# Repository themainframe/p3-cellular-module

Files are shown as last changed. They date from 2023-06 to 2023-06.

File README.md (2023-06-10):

# GPD Pocket 3 Cellular Module

This is a plug-in cellular module for the [GPD Pocket 3](https://gpd.hk/gpdpocket3). It provides LTE Cat. 4 cellular connectivity using a Quectel EC25 (or compatible) module.

It's still a little bit of a prototype at this stage, but initial results are promising!

You can read more about it [on my blog](https://damow.net/gpd-pocket-3-cellular-module).

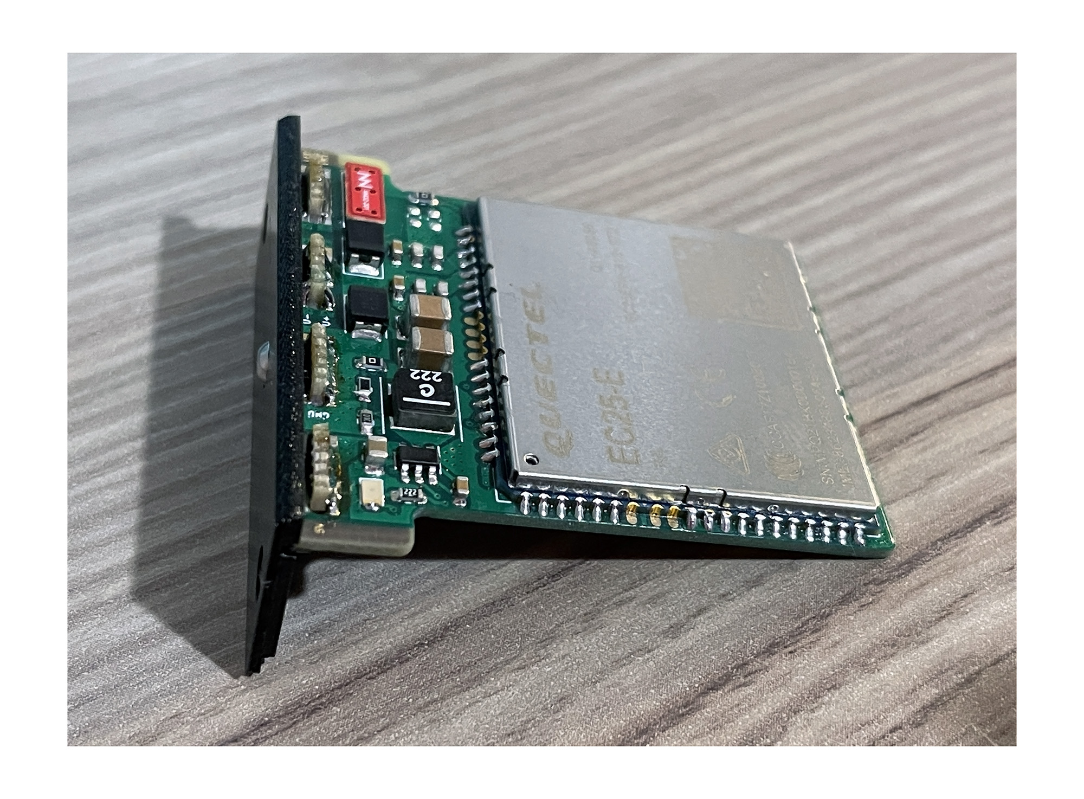
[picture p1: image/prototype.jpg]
Assembled prototype based on Rev1


## Stackup & BOM

4 layers. JLC JLC04101H-7628 Impedance Controlled FR4.

HTML BOMs can be found in the `bom/` directory.

## Questions?

Open an issue or drop me an email - `me@` my blog domain.

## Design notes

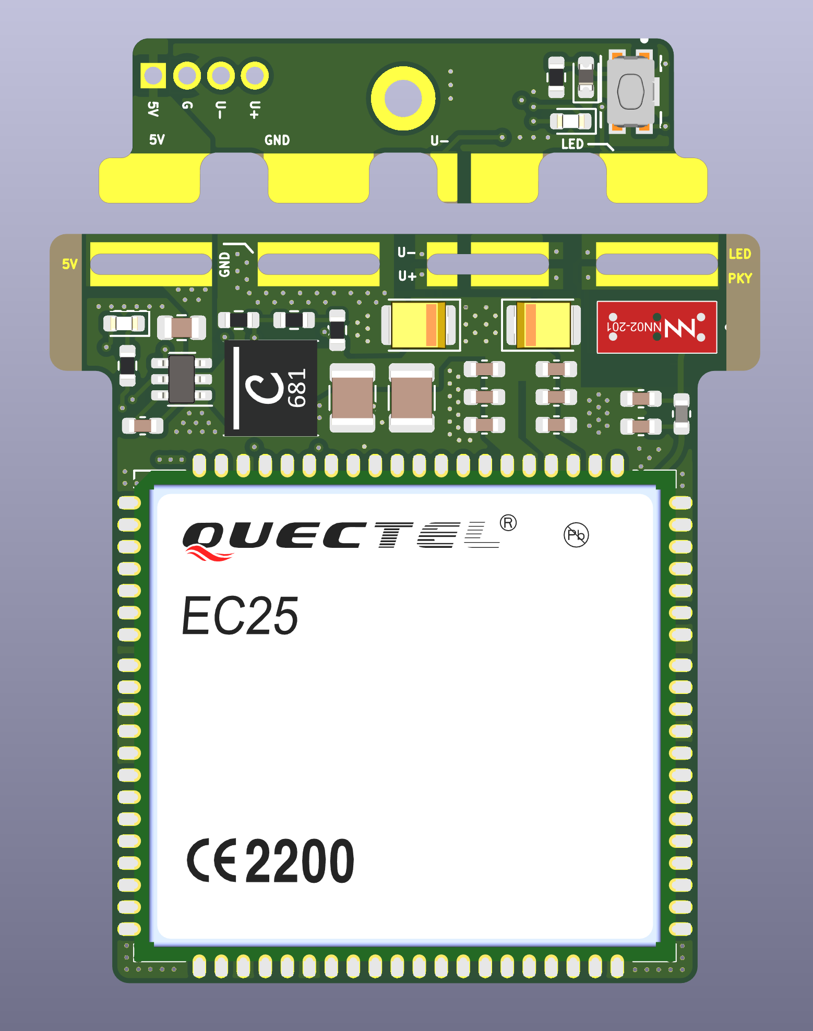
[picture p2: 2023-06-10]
gerber/rev2/2d/bottom.png

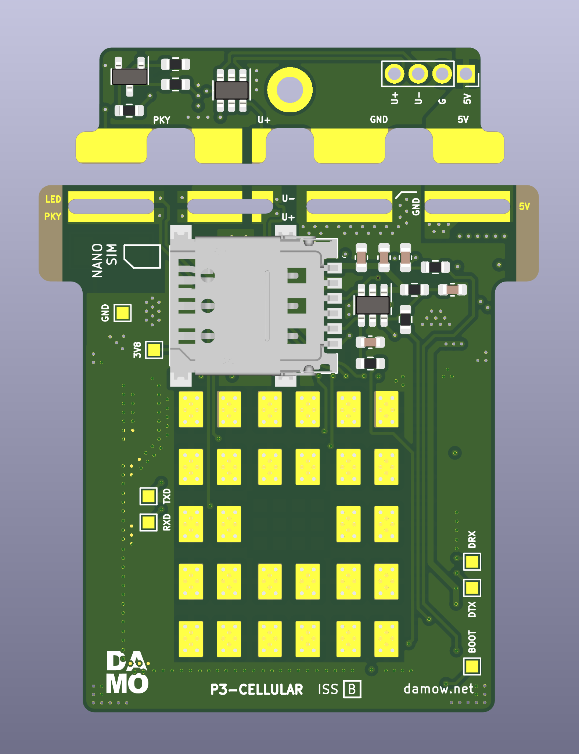
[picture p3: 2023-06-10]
gerber/rev2/2d/top.png

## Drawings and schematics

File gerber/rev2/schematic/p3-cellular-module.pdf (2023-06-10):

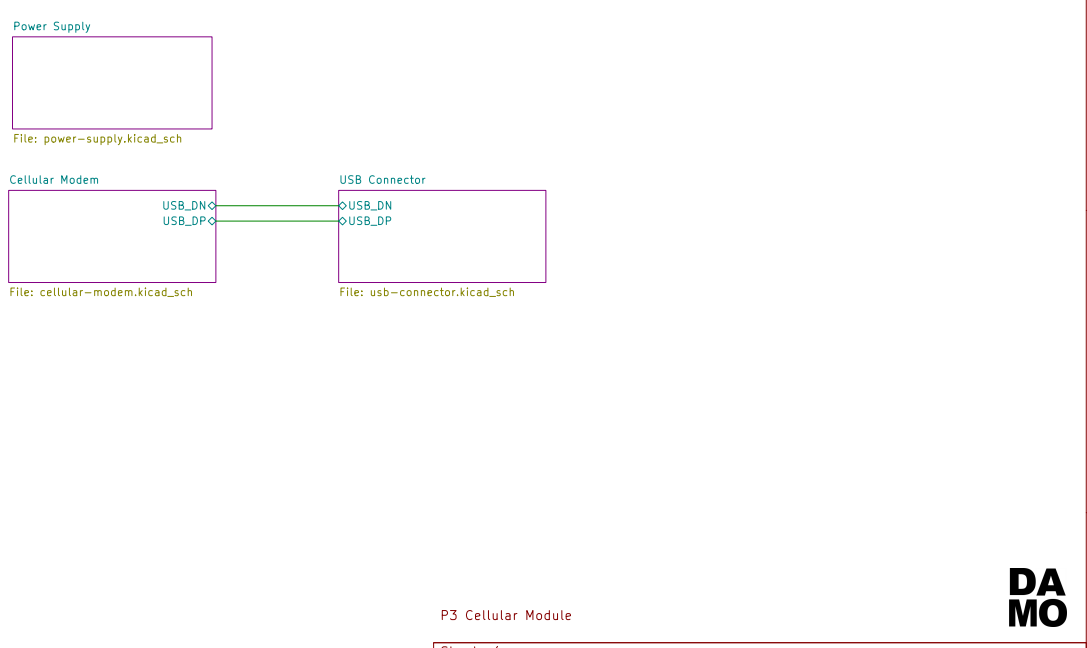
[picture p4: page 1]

USB_DP USB Connector File: usb-connector.kicad_sch

File: p3-cellular-module.kicad_sch Sheet: / P3 Cellular Module

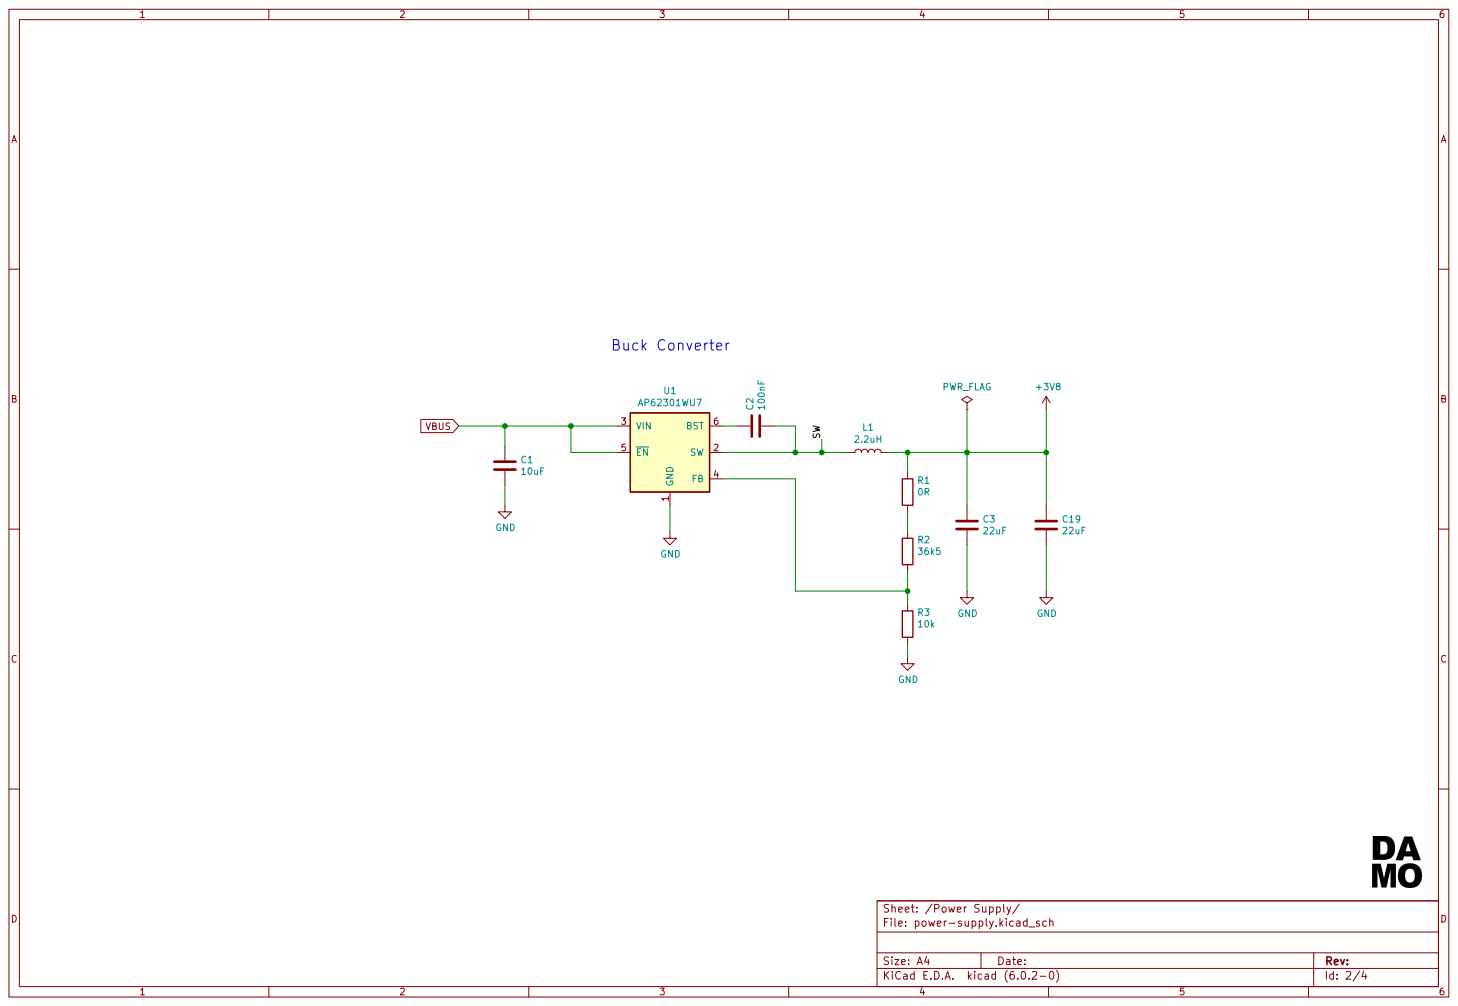
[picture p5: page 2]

1 SW 2 VIN 3 FB 4 ~{EN} 5 BST 6 U1 AP62301WU7 +3V8

Id: 2/4 File: power-supply.kicad_sch

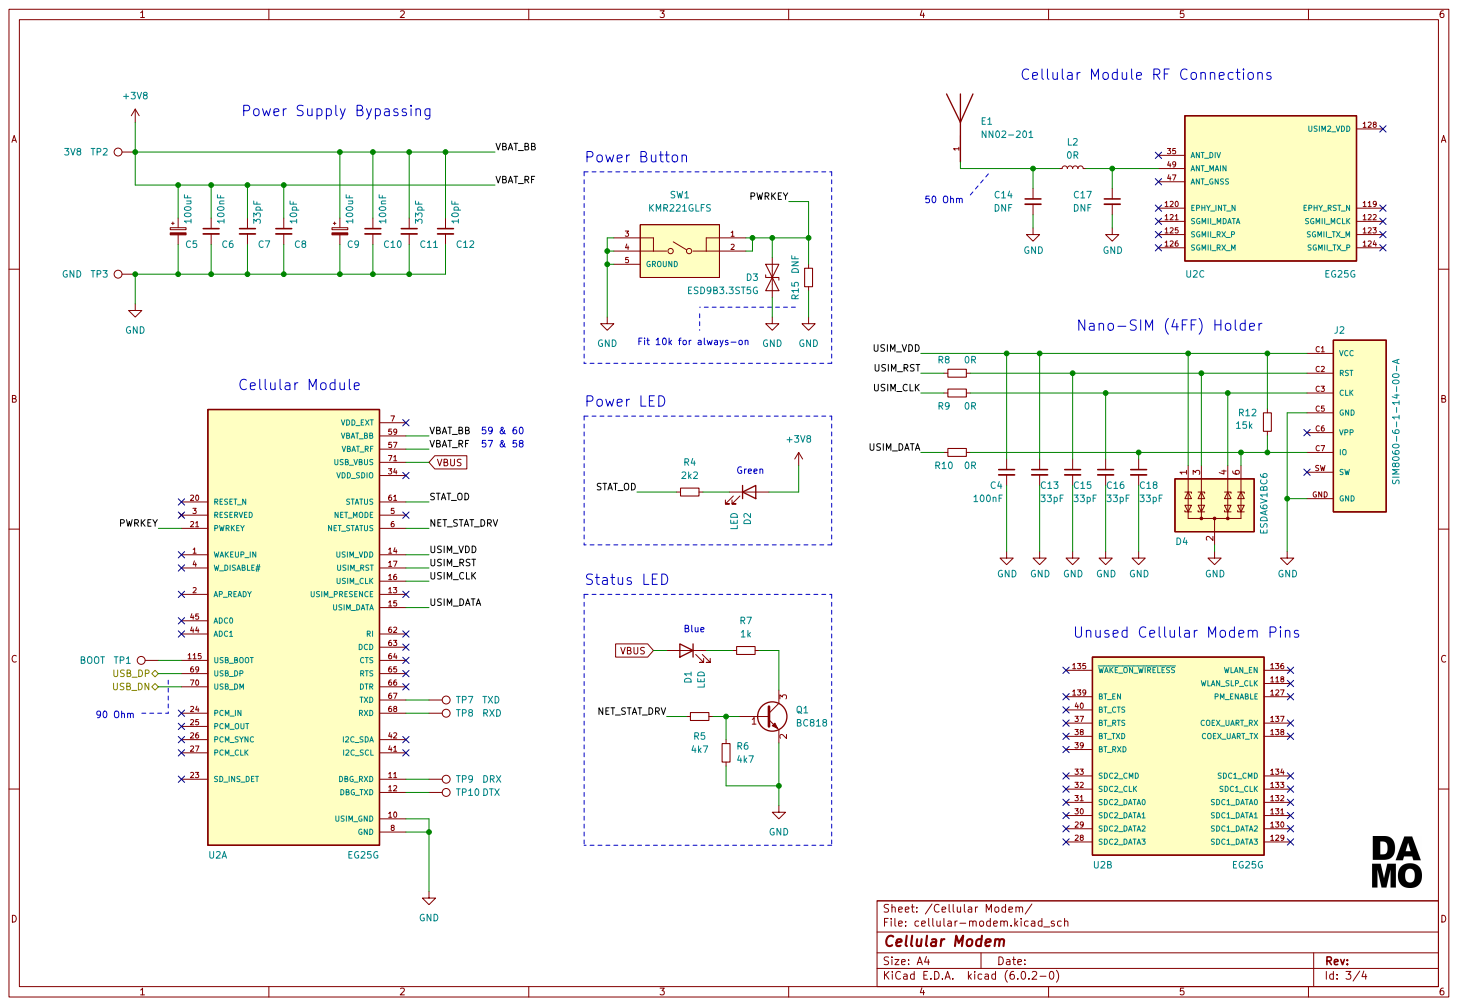
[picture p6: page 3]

Fit 10k for always-on

GND GND

Unused Cellular Modem Pins

File: cellular-modem.kicad_sch Sheet: /Cellular Modem/ GND

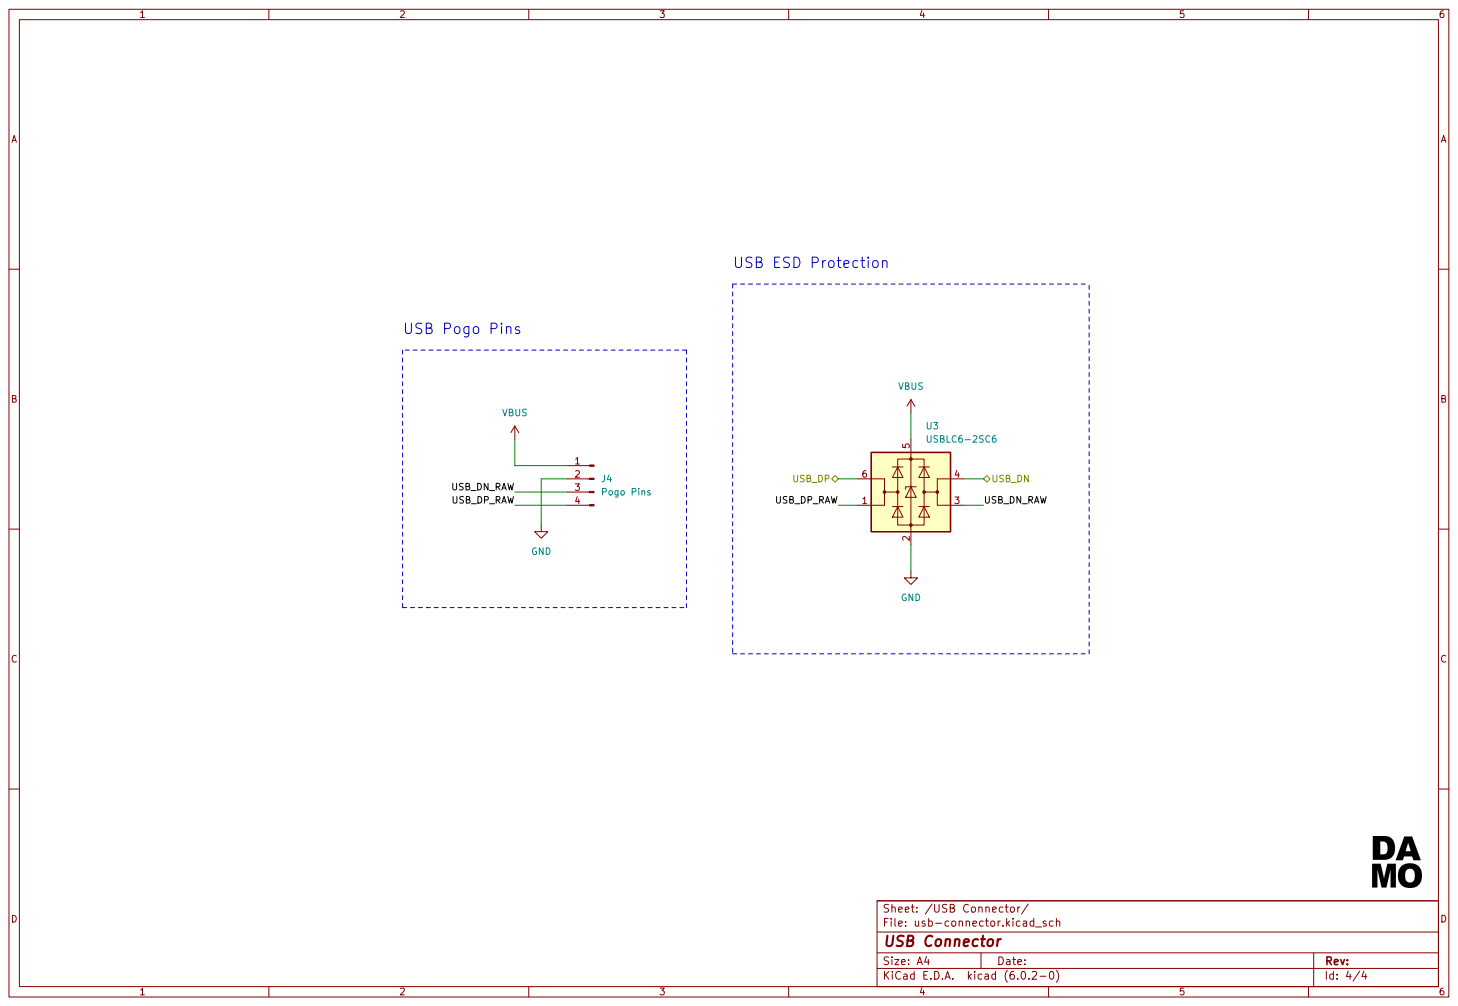
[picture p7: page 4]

File: usb-connector.kicad_sch Sheet: /USB Connector/ GND

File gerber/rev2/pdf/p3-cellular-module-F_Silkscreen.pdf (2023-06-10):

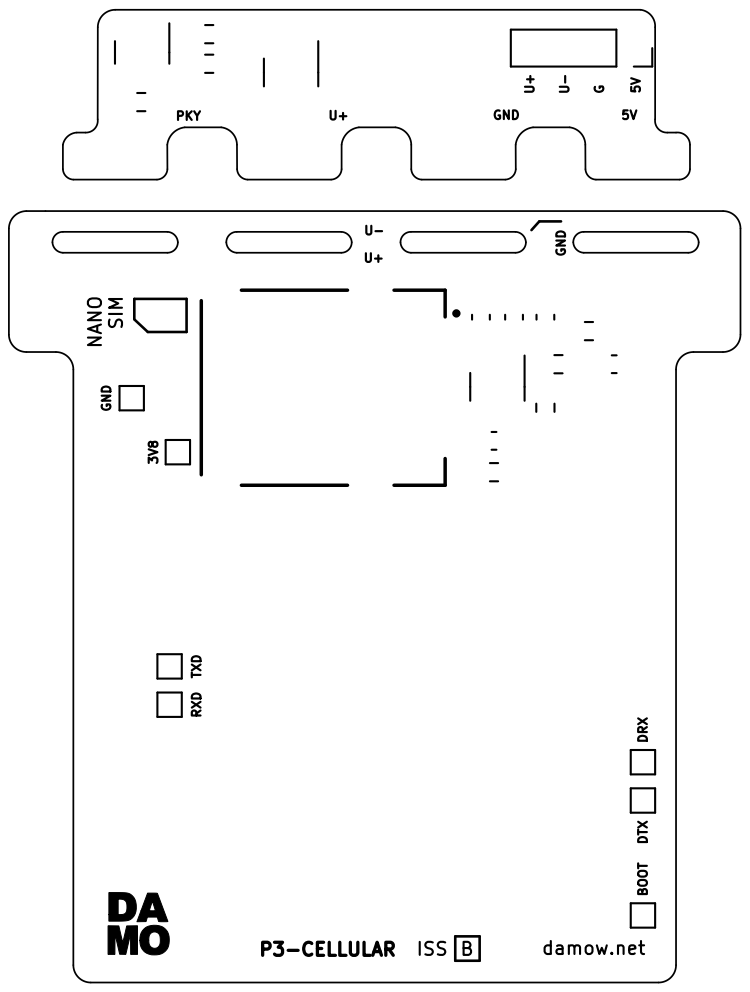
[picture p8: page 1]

G GND GND NANO SIM

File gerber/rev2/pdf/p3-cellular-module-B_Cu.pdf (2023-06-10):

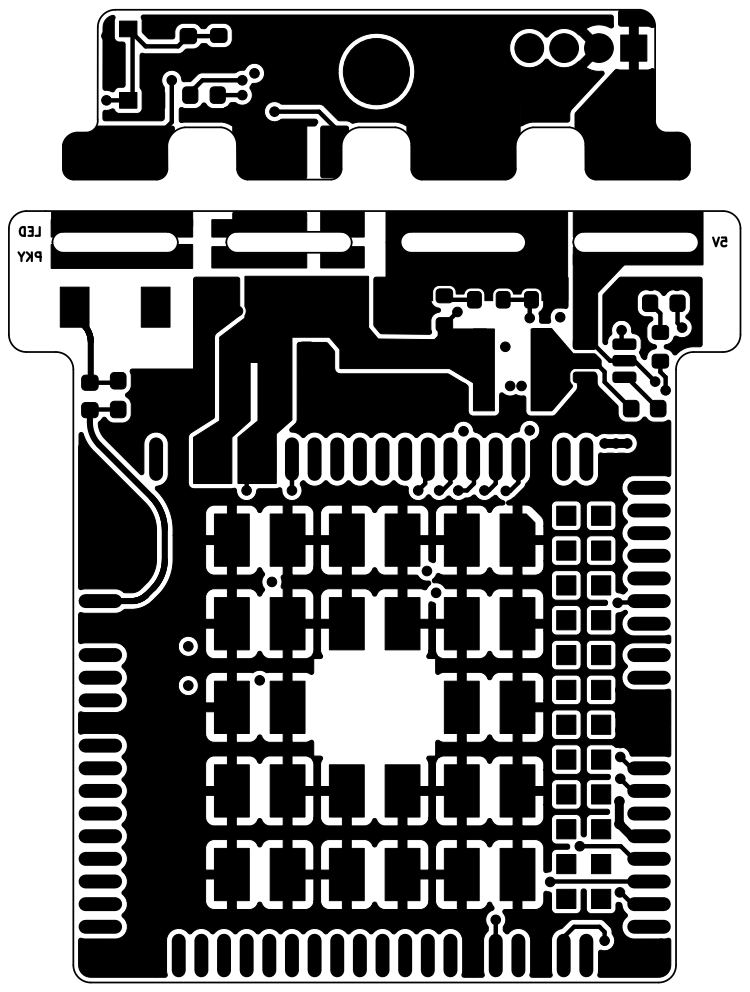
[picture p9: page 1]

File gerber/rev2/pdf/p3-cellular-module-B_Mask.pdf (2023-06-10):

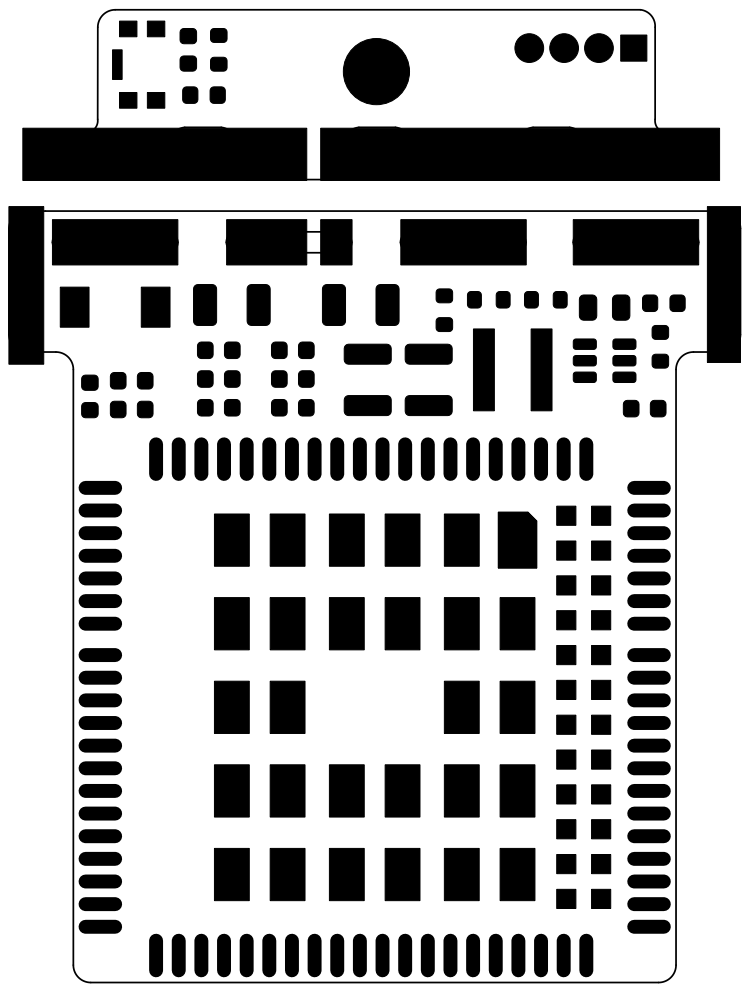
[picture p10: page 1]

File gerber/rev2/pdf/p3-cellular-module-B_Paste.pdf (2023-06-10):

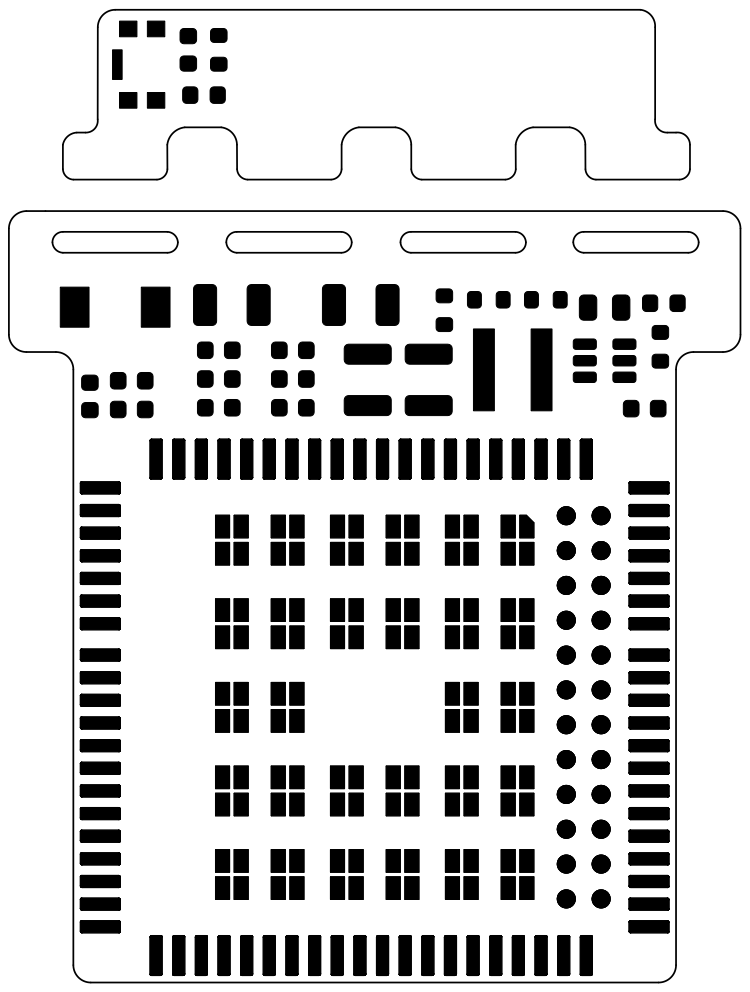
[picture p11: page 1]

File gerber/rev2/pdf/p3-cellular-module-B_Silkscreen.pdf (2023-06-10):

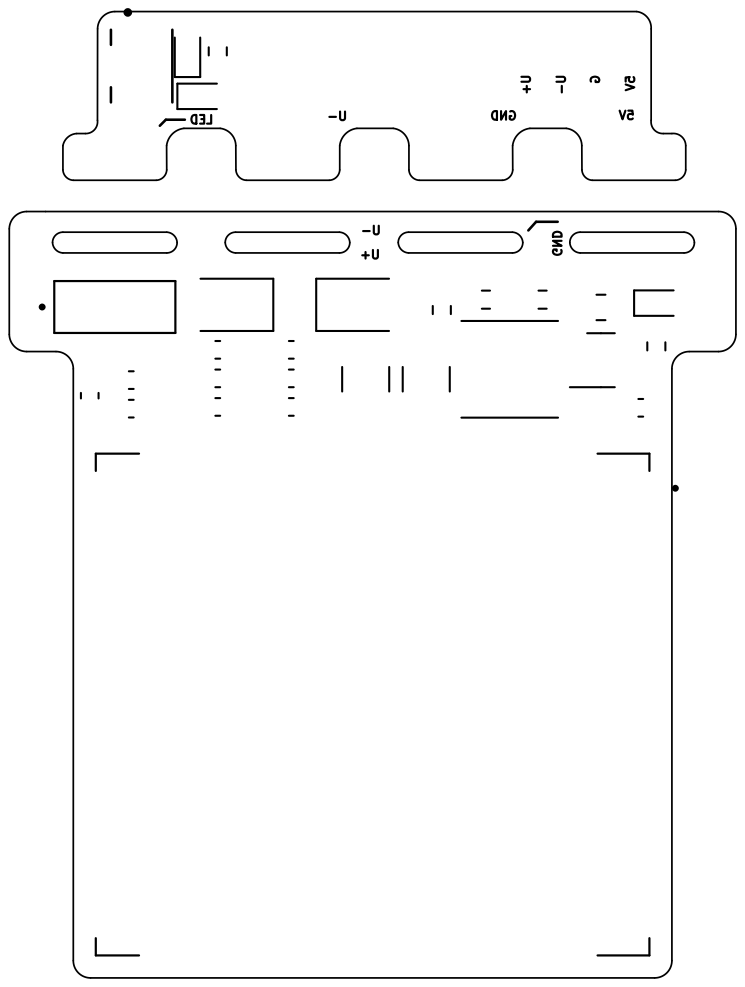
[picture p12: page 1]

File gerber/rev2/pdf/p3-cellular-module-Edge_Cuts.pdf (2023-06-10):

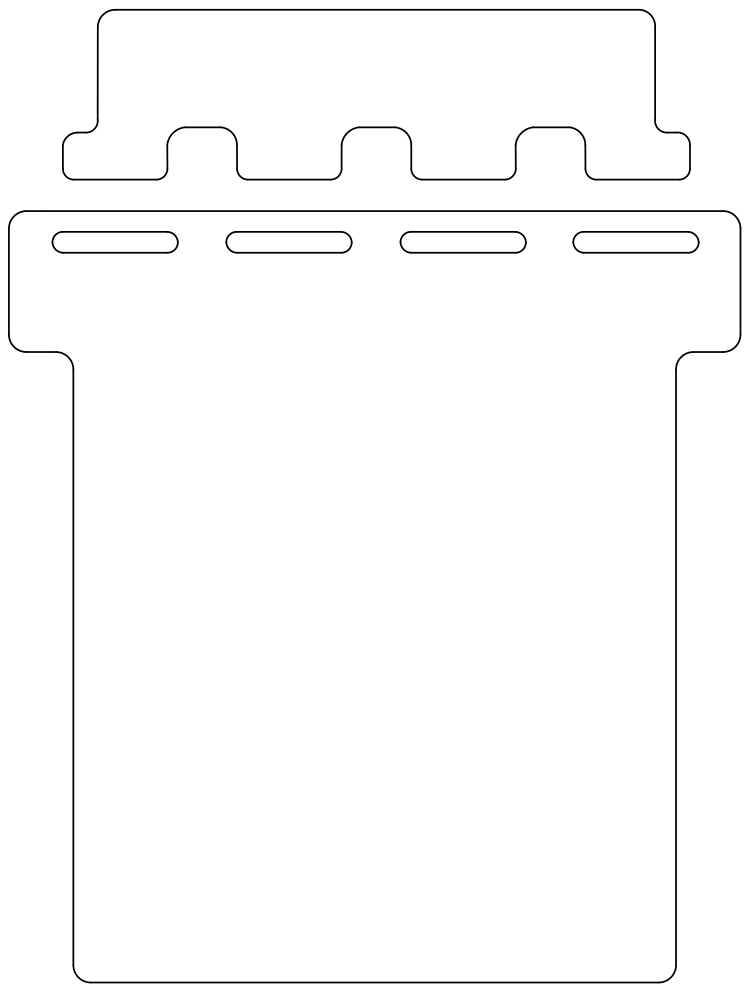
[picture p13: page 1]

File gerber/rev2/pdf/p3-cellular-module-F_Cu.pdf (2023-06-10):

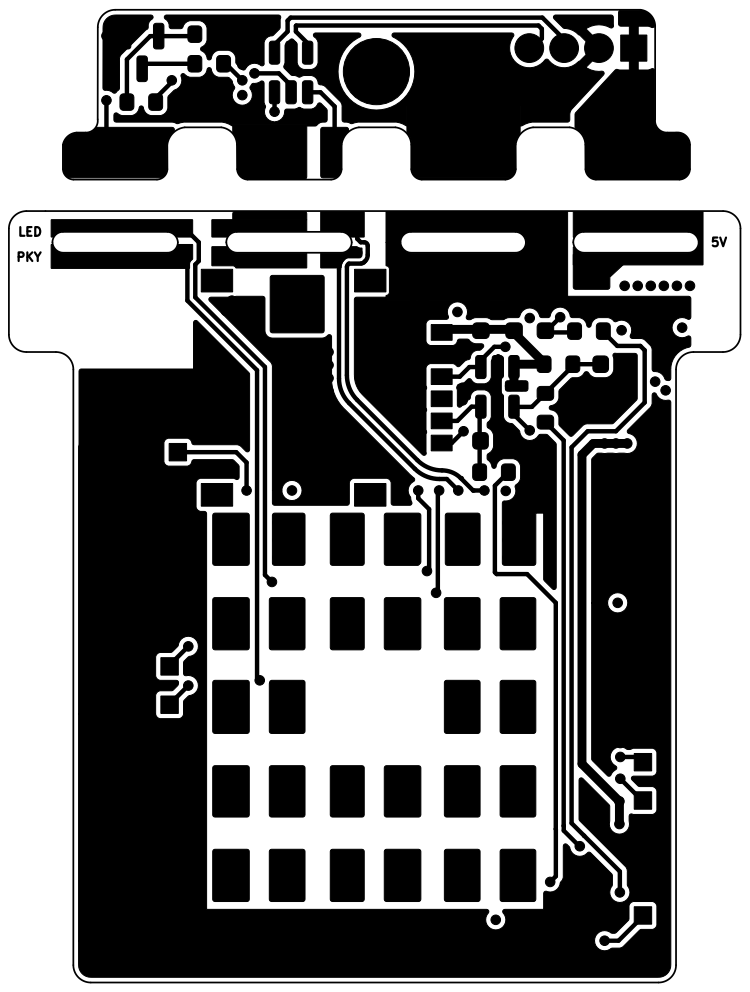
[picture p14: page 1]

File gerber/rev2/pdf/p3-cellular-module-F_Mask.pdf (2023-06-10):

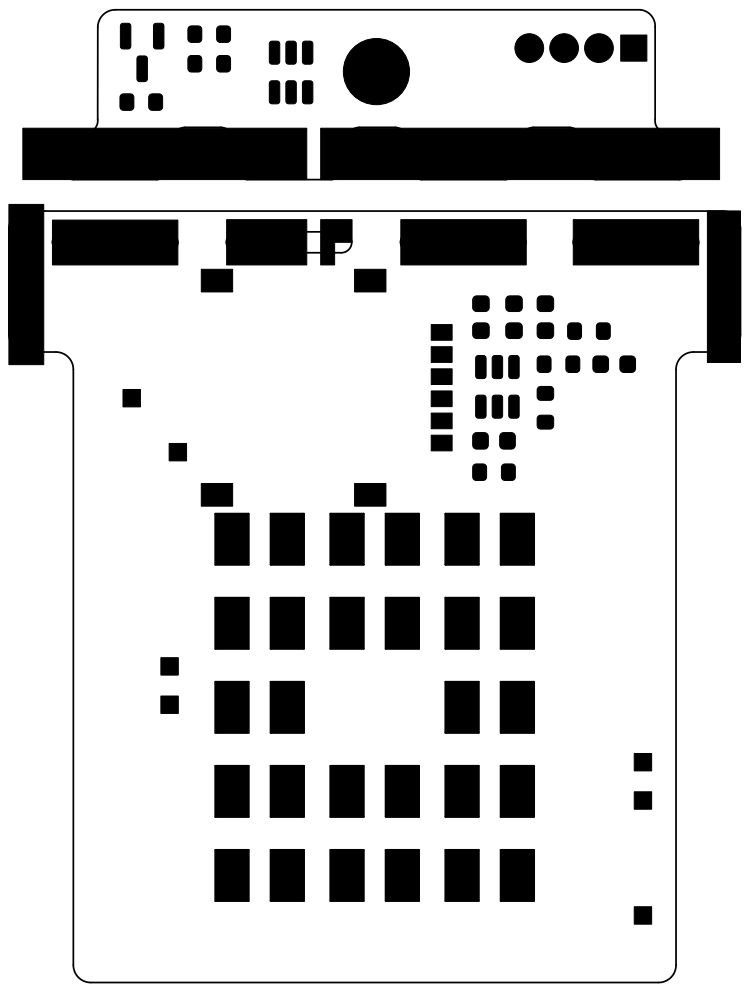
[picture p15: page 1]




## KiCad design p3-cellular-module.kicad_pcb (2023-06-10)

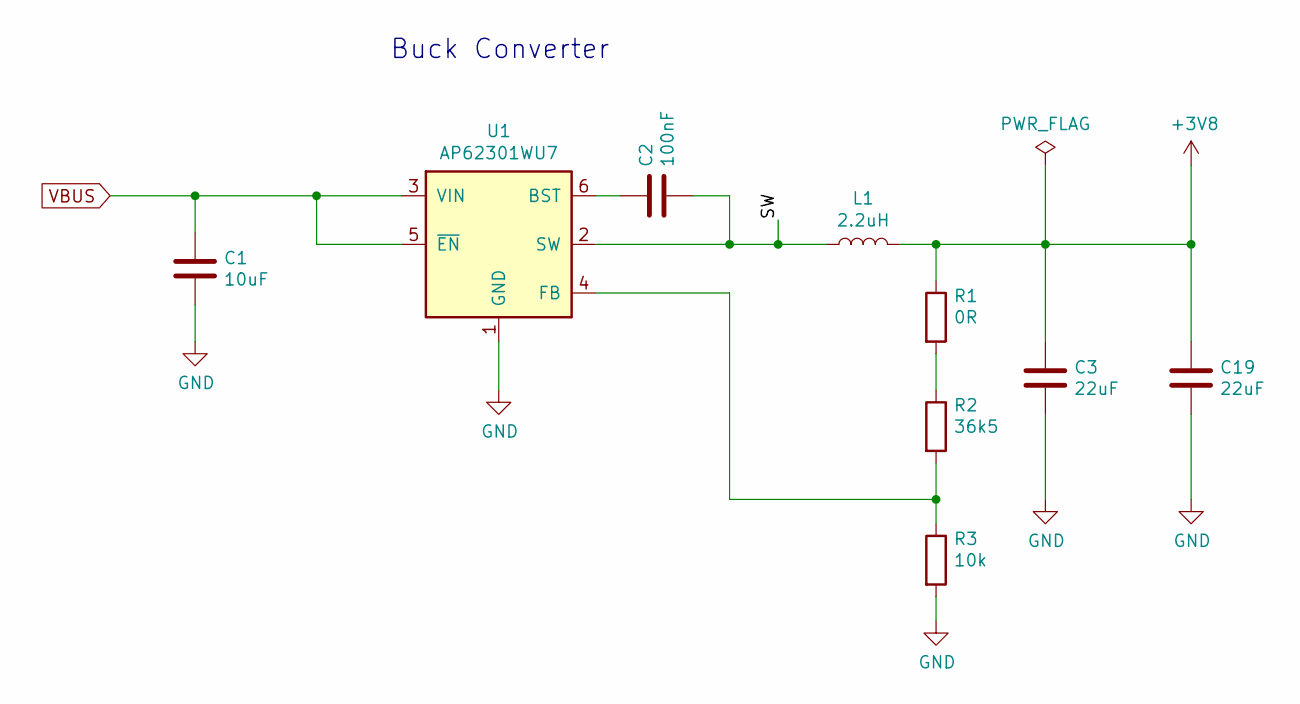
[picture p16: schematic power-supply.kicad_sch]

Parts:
C1: 10uF; C_0805_2012Metric; MPN GRM21BR71A106KA73K
C2: 100nF; C_0603_1608Metric; MPN C0603C104K3RAC
C3, C19: 22uF; C_1210_3225Metric; MPN CL32B226MOJNNNE
L1: 2.2uH; L_Coilcraft_XAL5030; MPN XAL5030-222MEC
R1: 0R; R_0603_1608Metric
R2: 36k5; R_0603_1608Metric; MPN CRCW060336K5FKEA
R3: 10k; R_0603_1608Metric
U1: AP62301WU7; TSOT-23-6; MPN AP62301WU-7

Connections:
+3V8: C3.1, C19.1, L1.2, R1.1; also elsewhere on the board
/Power Supply/SW: C2.2, L1.1, U1.2 (SW)
GND: C1.2, C3.2, C19.2, R3.2, U1.1 (GND); also elsewhere on the board
unnamed: C2.1, U1.6 (BST)
unnamed: R1.2, R2.1
unnamed: R2.2, R3.1, U1.4 (FB)
VBUS: C1.1, U1.3 (VIN), U1.5 (~EN); also elsewhere on the board

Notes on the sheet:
Buck Converter

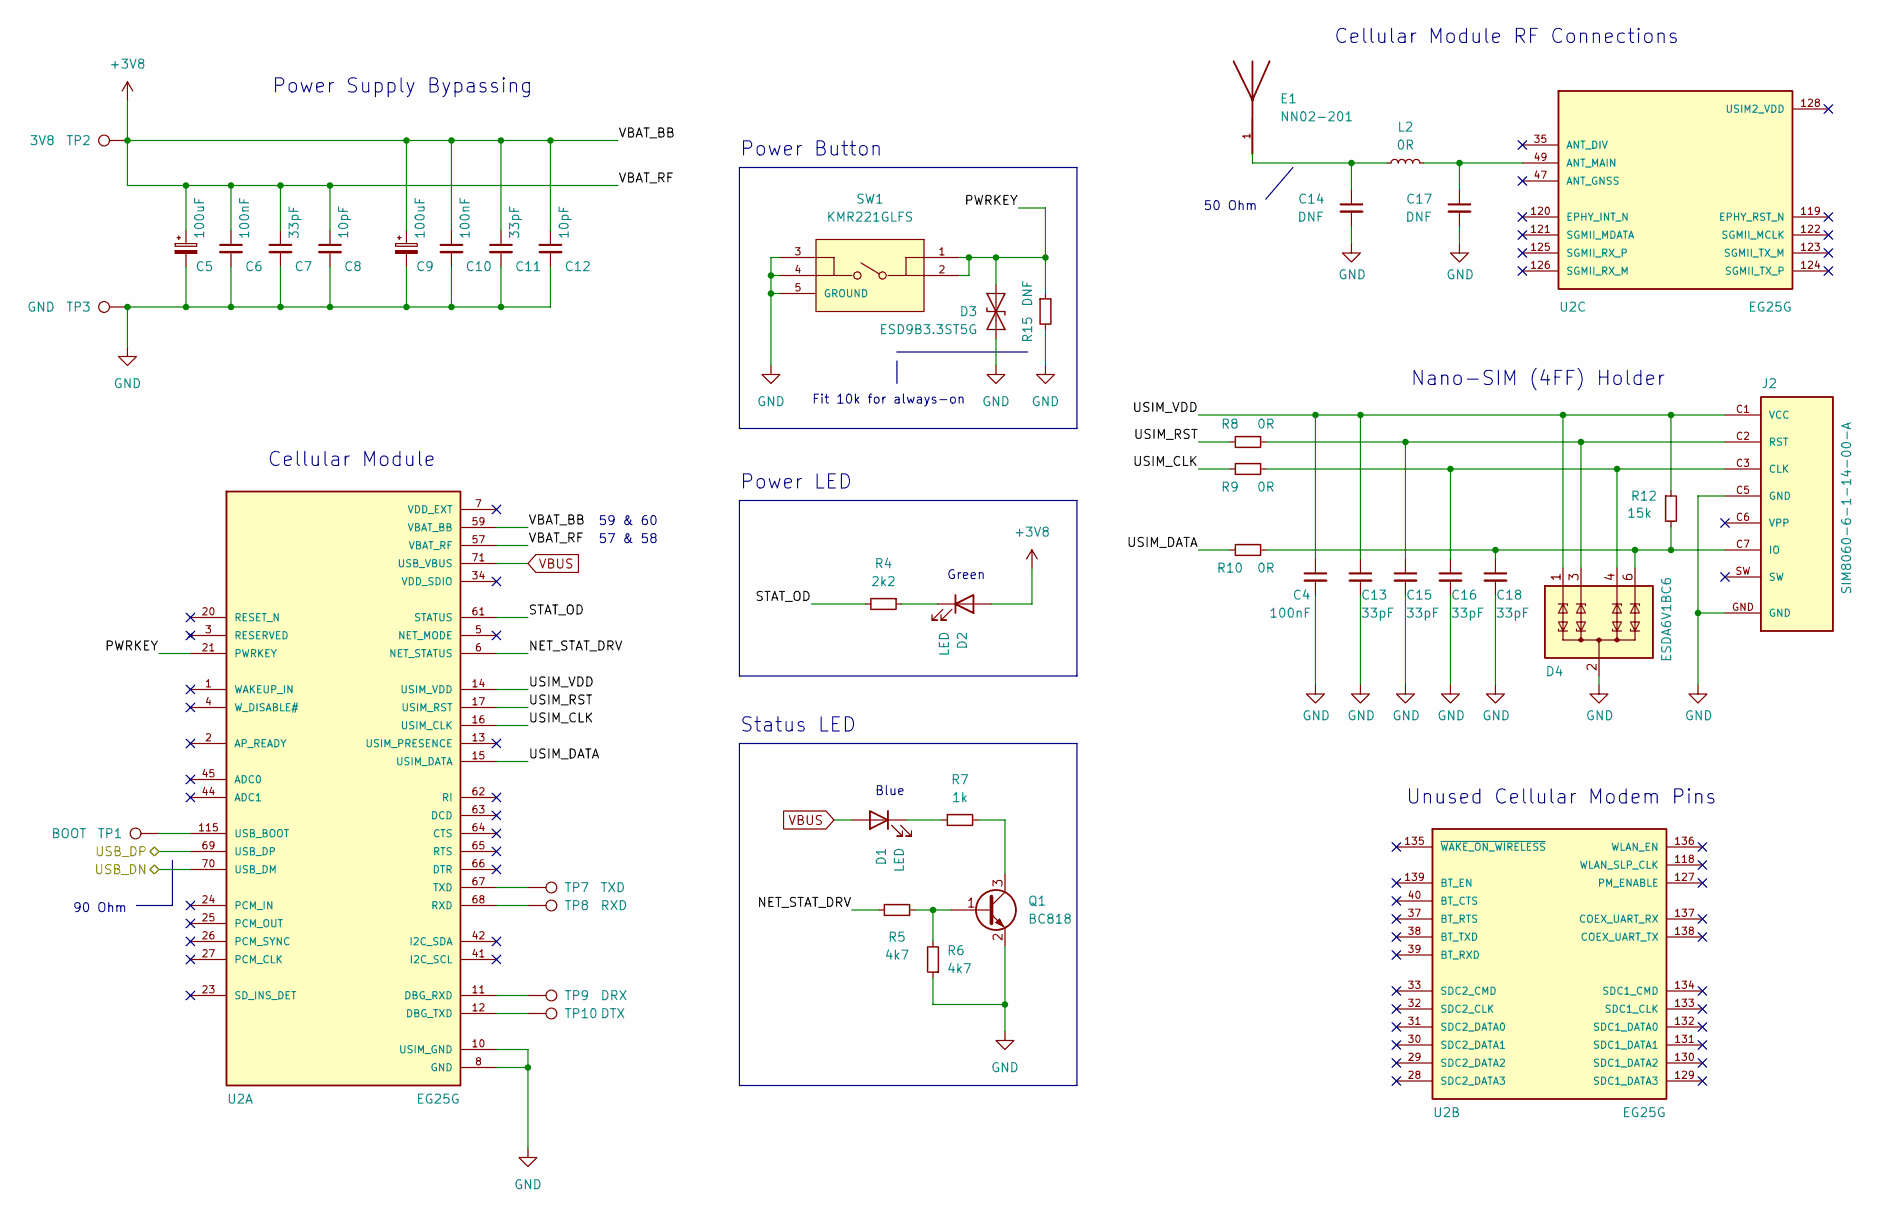
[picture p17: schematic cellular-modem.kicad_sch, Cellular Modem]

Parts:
C4, C6, C10: 100nF; C_0603_1608Metric; MPN C0603C104K3RAC
C5, C9: 100uF; CP_EIA-3528-21_Kemet-B; MPN TCJB107M006R0040
C7, C11, C13, C15, C16, C18: 33pF; C_0603_1608Metric; MPN 06035A330KAT2A
C8, C12: 10pF; C_0603_1608Metric
C14, C17: DNF; C_0603_1608Metric
D1, D2: LED; LED_0603_1608Metric
D3: ESD9B3.3ST5G; D_0603_1608Metric; MPN ESD9B3.3ST5G
D4: ESDA6V1BC6; SOT-23-6; MPN ESDA6V1BC6
E1: NN02-201; XCVR_NN02-201; MPN NN02-201
J2: SIM8060-6-1-14-00-A; GCT_SIM8060-6-1-14-00-A; MPN SIM8060-6-1-14-00-A
L2: 0R; L_0603_1608Metric
Q1: BC818; SOT-23; MPN BC818-40
R4: 2k2; R_0603_1608Metric
R5, R6: 4k7; R_0603_1608Metric
R7: 1k; R_0603_1608Metric
R8, R9, R10: 0R; R_0603_1608Metric
R12: 15k; R_0603_1608Metric
R15: DNF; R_0603_1608Metric
SW1: KMR221GLFS; CK-KMR221GLFS-MFG; MPN KMR221GLFS
TP1: BOOT; TestPoint_Pad_1.0x1.0mm
TP2: 3V8; TestPoint_Pad_1.0x1.0mm
TP3: GND; TestPoint_Pad_1.0x1.0mm
TP7: TXD; TestPoint_Pad_1.0x1.0mm
TP8: RXD; TestPoint_Pad_1.0x1.0mm
TP9: DRX; TestPoint_Pad_1.0x1.0mm
TP10: DTX; TestPoint_Pad_1.0x1.0mm
U2: EG25G; XCVR_EG25G; MPN EG25G

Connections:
+3V8: C5.1, C6.1, C7.1, C8.1, C9.1, C10.1, C11.1, C12.1, D2.2 (A), TP2.1, U2.57 (VBAT_RF), U2.58 (VBAT_RF), U2.59 (VBAT_BB), U2.60 (VBAT_BB); also elsewhere on the board
/Cellular Modem/NET_STAT_DRV: R5.2, U2.6 (NET_STATUS)
/Cellular Modem/PWRKEY: D3.2 (A2), R15.1, SW1.1, SW1.2, U2.21 (PWRKEY)
/Cellular Modem/STAT_OD: R4.2, U2.61 (STATUS)
/Cellular Modem/USB_DN: U2.70 (USB_DM); also elsewhere on the board
/Cellular Modem/USB_DP: U2.69 (USB_DP); also elsewhere on the board
/Cellular Modem/USIM_CLK: R9.2, U2.16 (USIM_CLK)
/Cellular Modem/USIM_DATA: R10.2, U2.15 (USIM_DATA)
/Cellular Modem/USIM_RST: R8.2, U2.17 (USIM_RST)
/Cellular Modem/USIM_VDD: C4.1, C13.1, D4.1 (TVS1), J2.C1 (VCC), R12.1, U2.14 (USIM_VDD)
GND: C4.2, C5.2, C6.2, C7.2, C8.2, C9.2, C10.2, C11.2, C12.2, C13.2, C14.2, C15.2, C16.2, C17.2, C18.2, D3.1 (A1), D4.2 (COM), D4.5 (COM), J2.C5 (GND), J2.GND, Q1.2 (E), R6.1, R15.2, SW1.3, SW1.4, SW1.5 (GROUND), TP3.1, U2.8 (GND), U2.9 (GND), U2.10 (USIM_GND), U2.19 (GND), U2.22 (GND), U2.36 (GND), U2.46 (GND), U2.48 (GND), U2.50 (GND), U2.51 (GND), U2.52 (GND), U2.53 (GND), U2.54 (GND), U2.56 (GND), U2.72 (GND), U2.85 (GND), U2.86 (GND), U2.87 (GND), U2.88 (GND), U2.89 (GND), U2.90 (GND), U2.91 (GND), U2.92 (GND), U2.93 (GND), U2.94 (GND), U2.95 (GND), U2.96 (GND), U2.97 (GND), U2.98 (GND), U2.99 (GND), U2.100 (GND), U2.101 (GND), U2.102 (GND), U2.103 (GND), U2.104 (GND), U2.105 (GND), U2.106 (GND), U2.107 (GND), U2.108 (GND), U2.109 (GND), U2.110 (GND), U2.111 (GND), U2.112 (GND); also elsewhere on the board
unnamed: C14.1, E1.1, L2.1
unnamed: C15.1, D4.3 (TVS2), J2.C2 (RST), R8.1
unnamed: C16.1, D4.4 (TVS3), J2.C3 (CLK), R9.1
unnamed: C17.1, L2.2, U2.49 (ANT_MAIN)
unnamed: C18.1, D4.6 (TVS4), J2.C7 (IO), R10.1, R12.2
unnamed: D1.1 (K), R7.1
unnamed: D2.1 (K), R4.1
unnamed: Q1.1 (B), R5.1, R6.2
unnamed: Q1.3 (C), R7.2
unnamed: TP1.1, U2.115 (USB_BOOT)
unnamed: TP7.1, U2.67 (TXD)
unnamed: TP8.1, U2.68 (RXD)
unnamed: TP9.1, U2.11 (DBG_RXD)
unnamed: TP10.1, U2.12 (DBG_TXD)
VBUS: D1.2 (A), U2.71 (USB_VBUS); also elsewhere on the board

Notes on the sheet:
Status LED
57 & 58
59 & 60
Green
Unused Cellular Modem Pins
Blue
90 Ohm
50 Ohm
Power LED
Power Supply Bypassing
Nano-SIM (4FF) Holder
Power Button
Cellular Module
Cellular Module RF Connections
Fit 10k for always-on

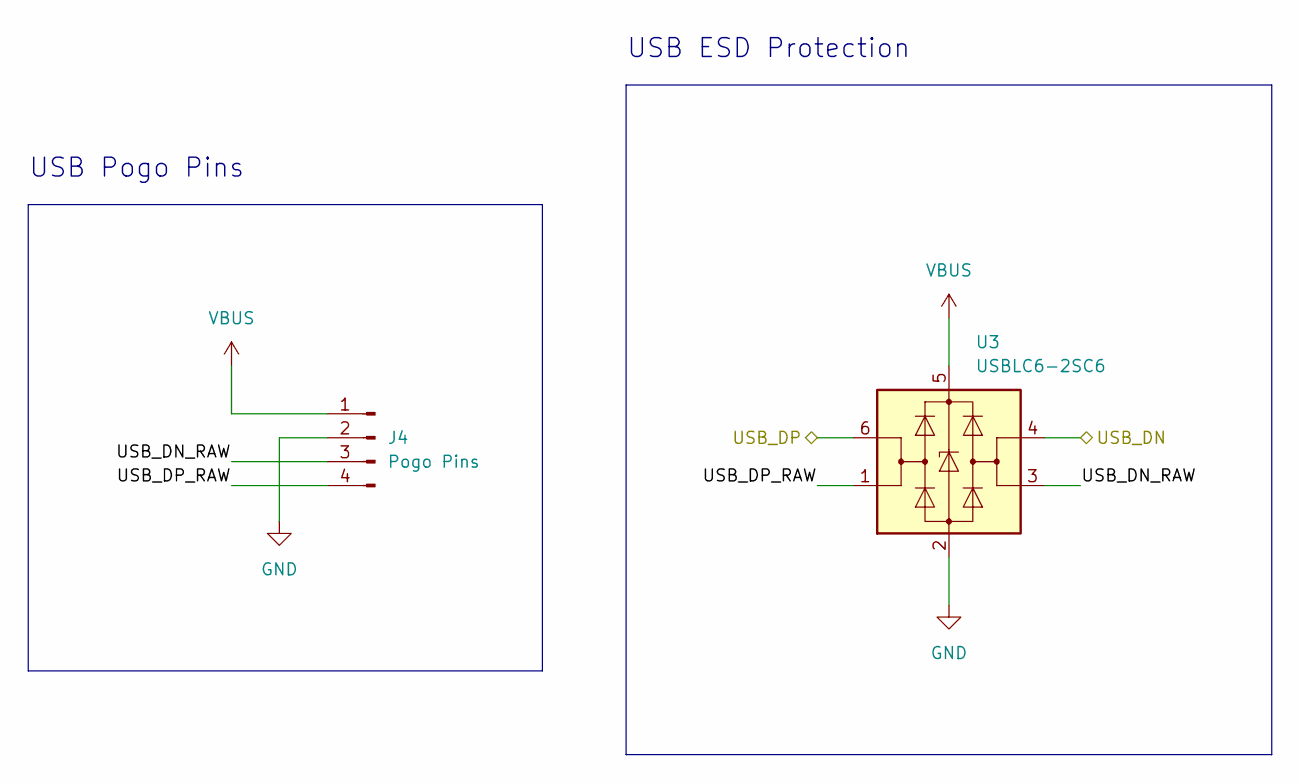
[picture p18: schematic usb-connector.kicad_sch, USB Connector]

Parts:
J4: Pogo Pins; PogoPins; MPN 836-22-004-10-001101
U3: USBLC6-2SC6; SOT-23-6; MPN USBLC6-2SC6

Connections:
/Cellular Modem/USB_DN: U3.4 (I/O2); also elsewhere on the board
/Cellular Modem/USB_DP: U3.6 (I/O1); also elsewhere on the board
/USB Connector/USB_DN_RAW: J4.3, U3.3 (I/O2)
/USB Connector/USB_DP_RAW: J4.4, U3.1 (I/O1)
GND: J4.2, U3.2 (GND); also elsewhere on the board
VBUS: J4.1, U3.5 (VBUS); also elsewhere on the board

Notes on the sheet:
USB ESD Protection
USB Pogo Pins

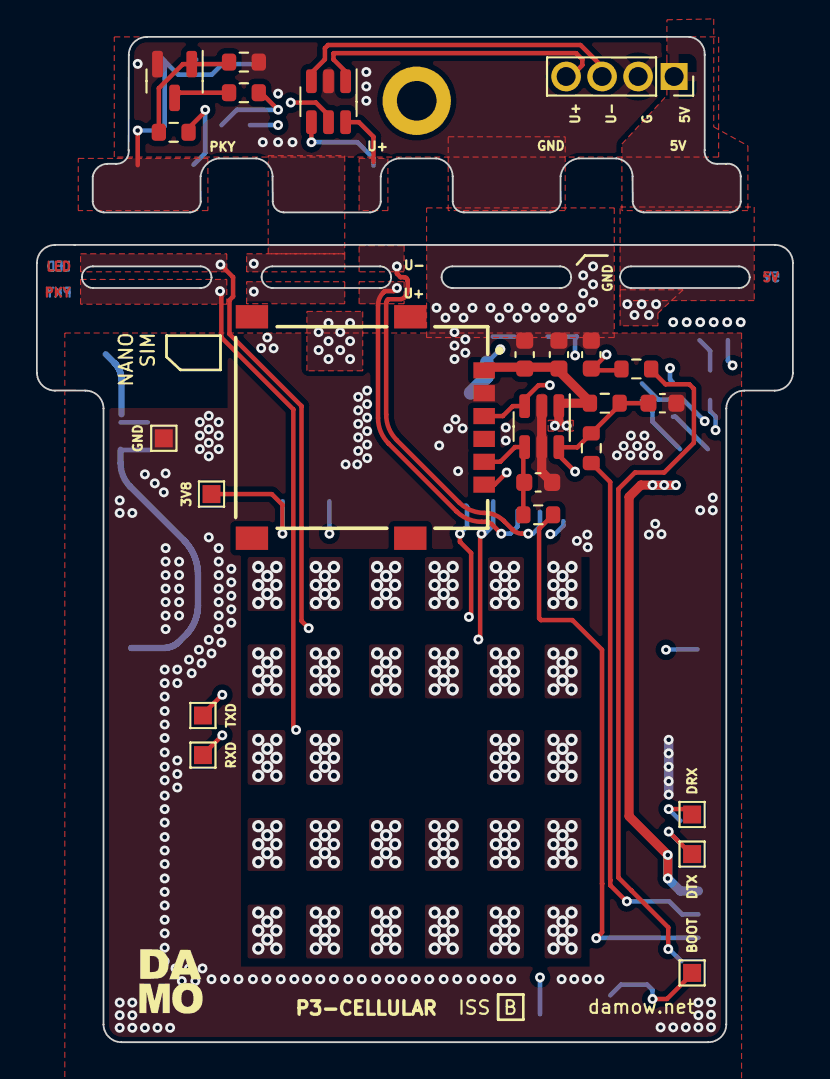
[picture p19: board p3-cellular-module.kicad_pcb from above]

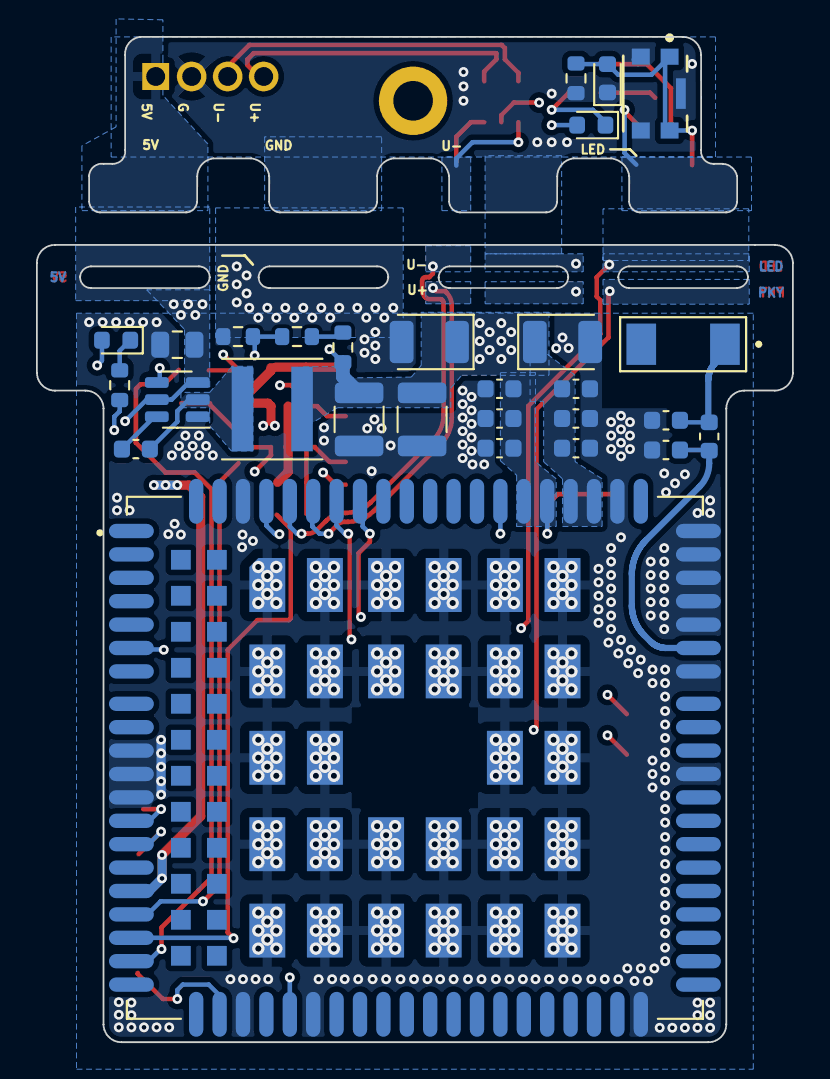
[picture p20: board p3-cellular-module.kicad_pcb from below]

Board: 4 copper layers, 42.0 x 55.8 mm, 52 parts (28 on the bottom side), 32 nets.

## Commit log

2022-06-17 Add: Improved layout
    [cellular-modem.kicad_sch, p3-cellular-module.kicad_pcb, p3-cellular-module.kicad_sch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]
2022-06-19 Update: Ground plane setup
    [cellular-modem.kicad_sch, p3-cellular-module.kicad_pcb, p3-cellular-module.kicad_sch]
2022-10-29 Add: Board size changes
    [cellular-modem.kicad_sch, p3-cellular-module.kicad_pcb, p3-cellular-module.kicad_sch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]
2022-10-30 Add: Mechanical changes pre-rev1 production run
    [p3-cellular-module-B_Cu.gbr, p3-cellular-module-B_Mask.gbr, p3-cellular-module-B_Paste.gbr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]
2022-11-25 Change: Separate boards rather than using mousebites
    [cellular-modem.kicad_sch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]
2023-06-10 Add: Gerbers for Rev2
    [cellular-modem.kicad_sch, p3-cellular-module.kicad_pcb, usb-connector.kicad_sch]
2023-06-10 Add: README and Prototype Image
